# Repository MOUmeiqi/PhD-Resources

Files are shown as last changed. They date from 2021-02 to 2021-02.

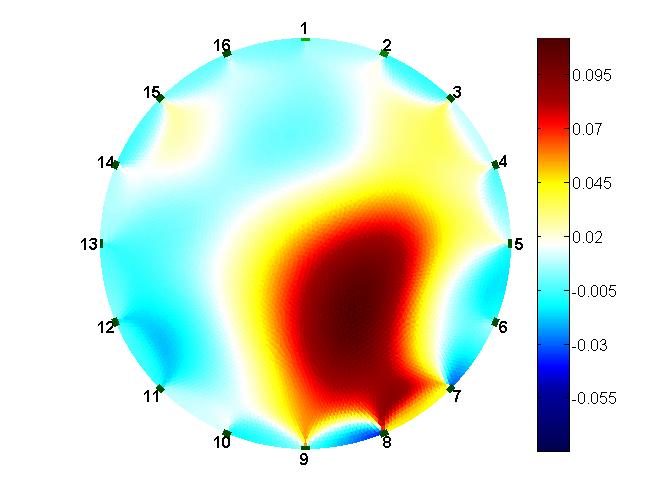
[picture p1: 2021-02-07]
Misc. Images/repeatability/r4/r42.jpg

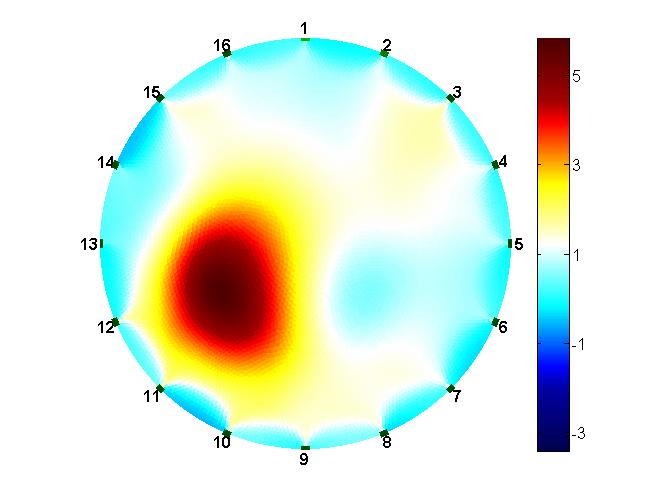
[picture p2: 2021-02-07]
Misc. Images/6-r64n.jpg

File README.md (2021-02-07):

# PhD-Resources
Source code repository for PhD on OCDM-aEITS

*** README ***

This repository (repo) contains the source code and some experimental results acquired during research of the thesis titled "Absolute Electrical Impedance Tomography and Spectroscopy - An Orthogonal Chirp Division Multiplexed (OCDM) Approach"
This thesis was authored by: Ezra Luke America and presented to the University of Cape Town for fulfilment of a Doctorate of Philosophy in Electrical Engineering.

The repo separated into four streams:
1) Source Codes
2) Misc. Experimental Results
3) Schematics
4) Misc. Images

*** Codes ***
The source codes components of the repo holds the source files that were used for the Arduino, MATLAB, uDAQ, and FPGA.
The code for the Arduino was used to control the system wide multiplexing.
The code for MATLAB was used to control the entire system and reconstruct images.
The code for the uDAQ_test_scripts were used to control a data acquisition card when initial tests were performed.
The code for the VHDL_CODE were used to control the ADC/DAC data acquisition board and FPGA.

*** Misc. Experimental Results ***
This folder contains 8 internal folders that hold a measurement frame for eight different positions of an anomaly.
To test this data, import the data to the MATLAB image_reconstruction code in the MATLAB folder.

*** Schematics ***
The schematics folder contains some system design schematics.

*** Misc. Images ***
This folder contains some reconstructed images using higher element FEM models.

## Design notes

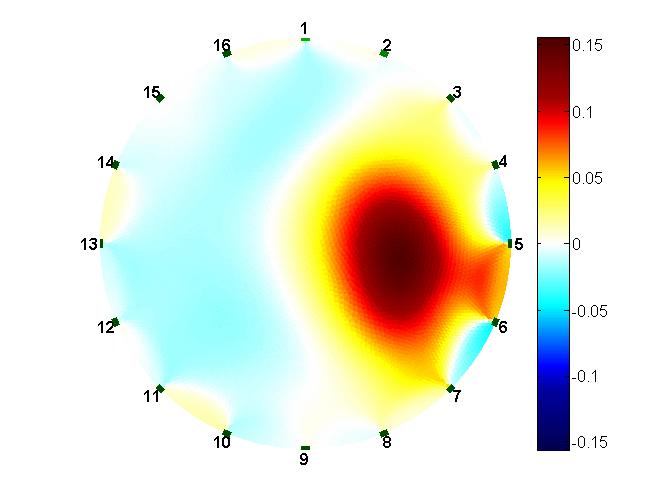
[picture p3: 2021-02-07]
Misc. Images/repeatability/r3/r35.jpg

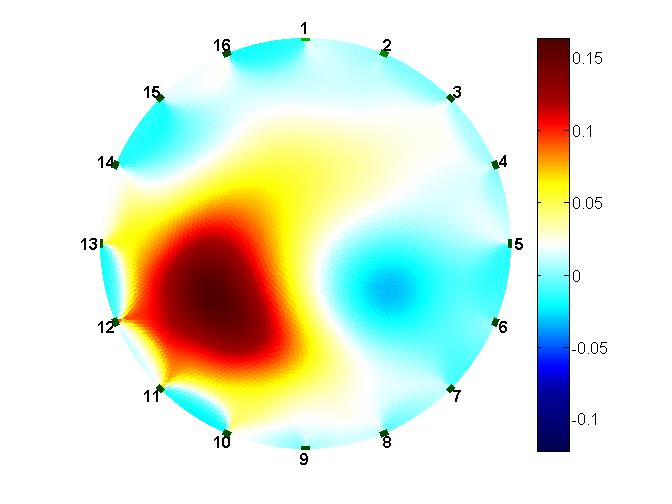
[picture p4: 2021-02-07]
Misc. Images/repeatability/r6/r62.jpg

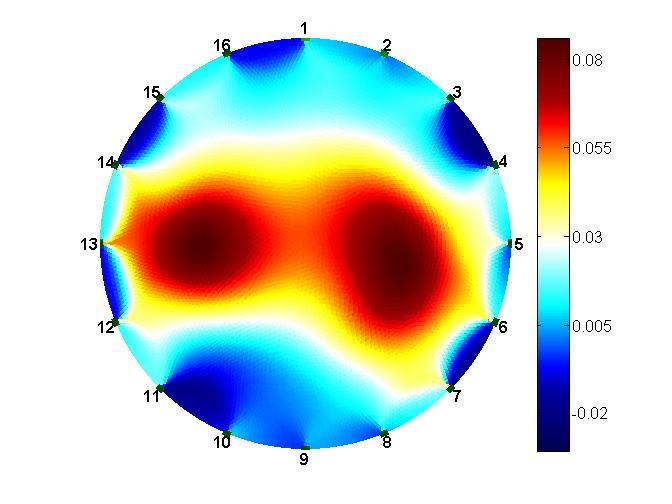
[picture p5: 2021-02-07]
Misc. Images/rdavg.jpg

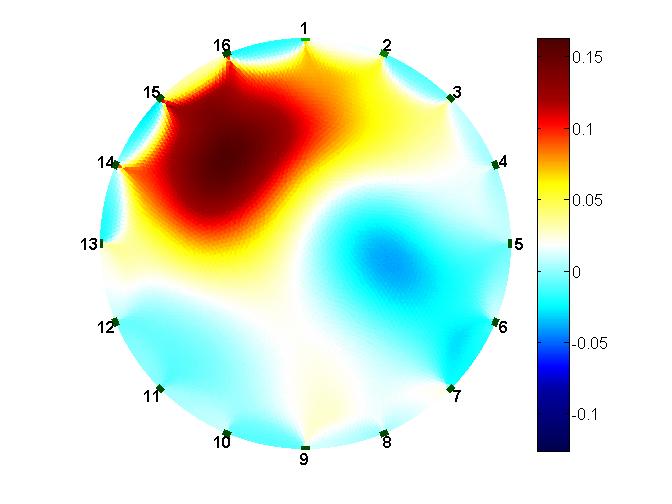
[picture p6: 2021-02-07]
Misc. Images/repeatability/r8/r82.jpg

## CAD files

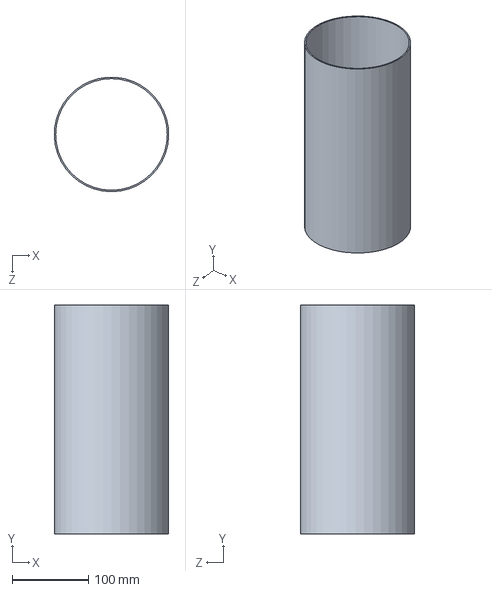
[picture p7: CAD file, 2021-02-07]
Schematics/electrodes/Part1.SLDPRT
149.9 x 300.0 x 149.8 mm

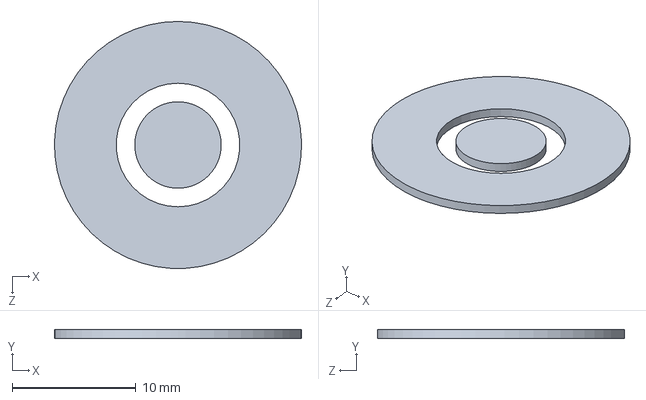
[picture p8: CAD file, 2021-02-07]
Schematics/electrodes/Part2.SLDPRT
20.0 x 0.7 x 20.0 mm

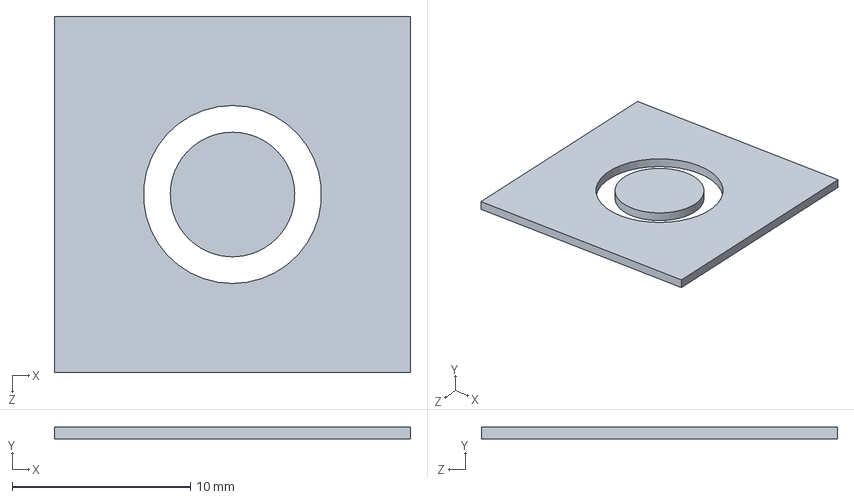
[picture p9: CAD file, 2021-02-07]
Schematics/electrodes/Part3.SLDPRT
20.0 x 0.7 x 20.0 mm

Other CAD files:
VHDL_CODE/db/step1_auto_stripped.stp
VHDL_CODE/step1_auto_stripped.stp
Schematics/electrodes/Circular Compound Internal Electrodes.DXF
VHDL_CODE/step1.stp
Schematics/electrodes/Uniform Current Density Electrodes.DXF
Schematics/electrodes/Circular Compound Internal Electrodes.SLDDRW
Schematics/electrodes/Uniform Current Density Electrodes.SLDDRW

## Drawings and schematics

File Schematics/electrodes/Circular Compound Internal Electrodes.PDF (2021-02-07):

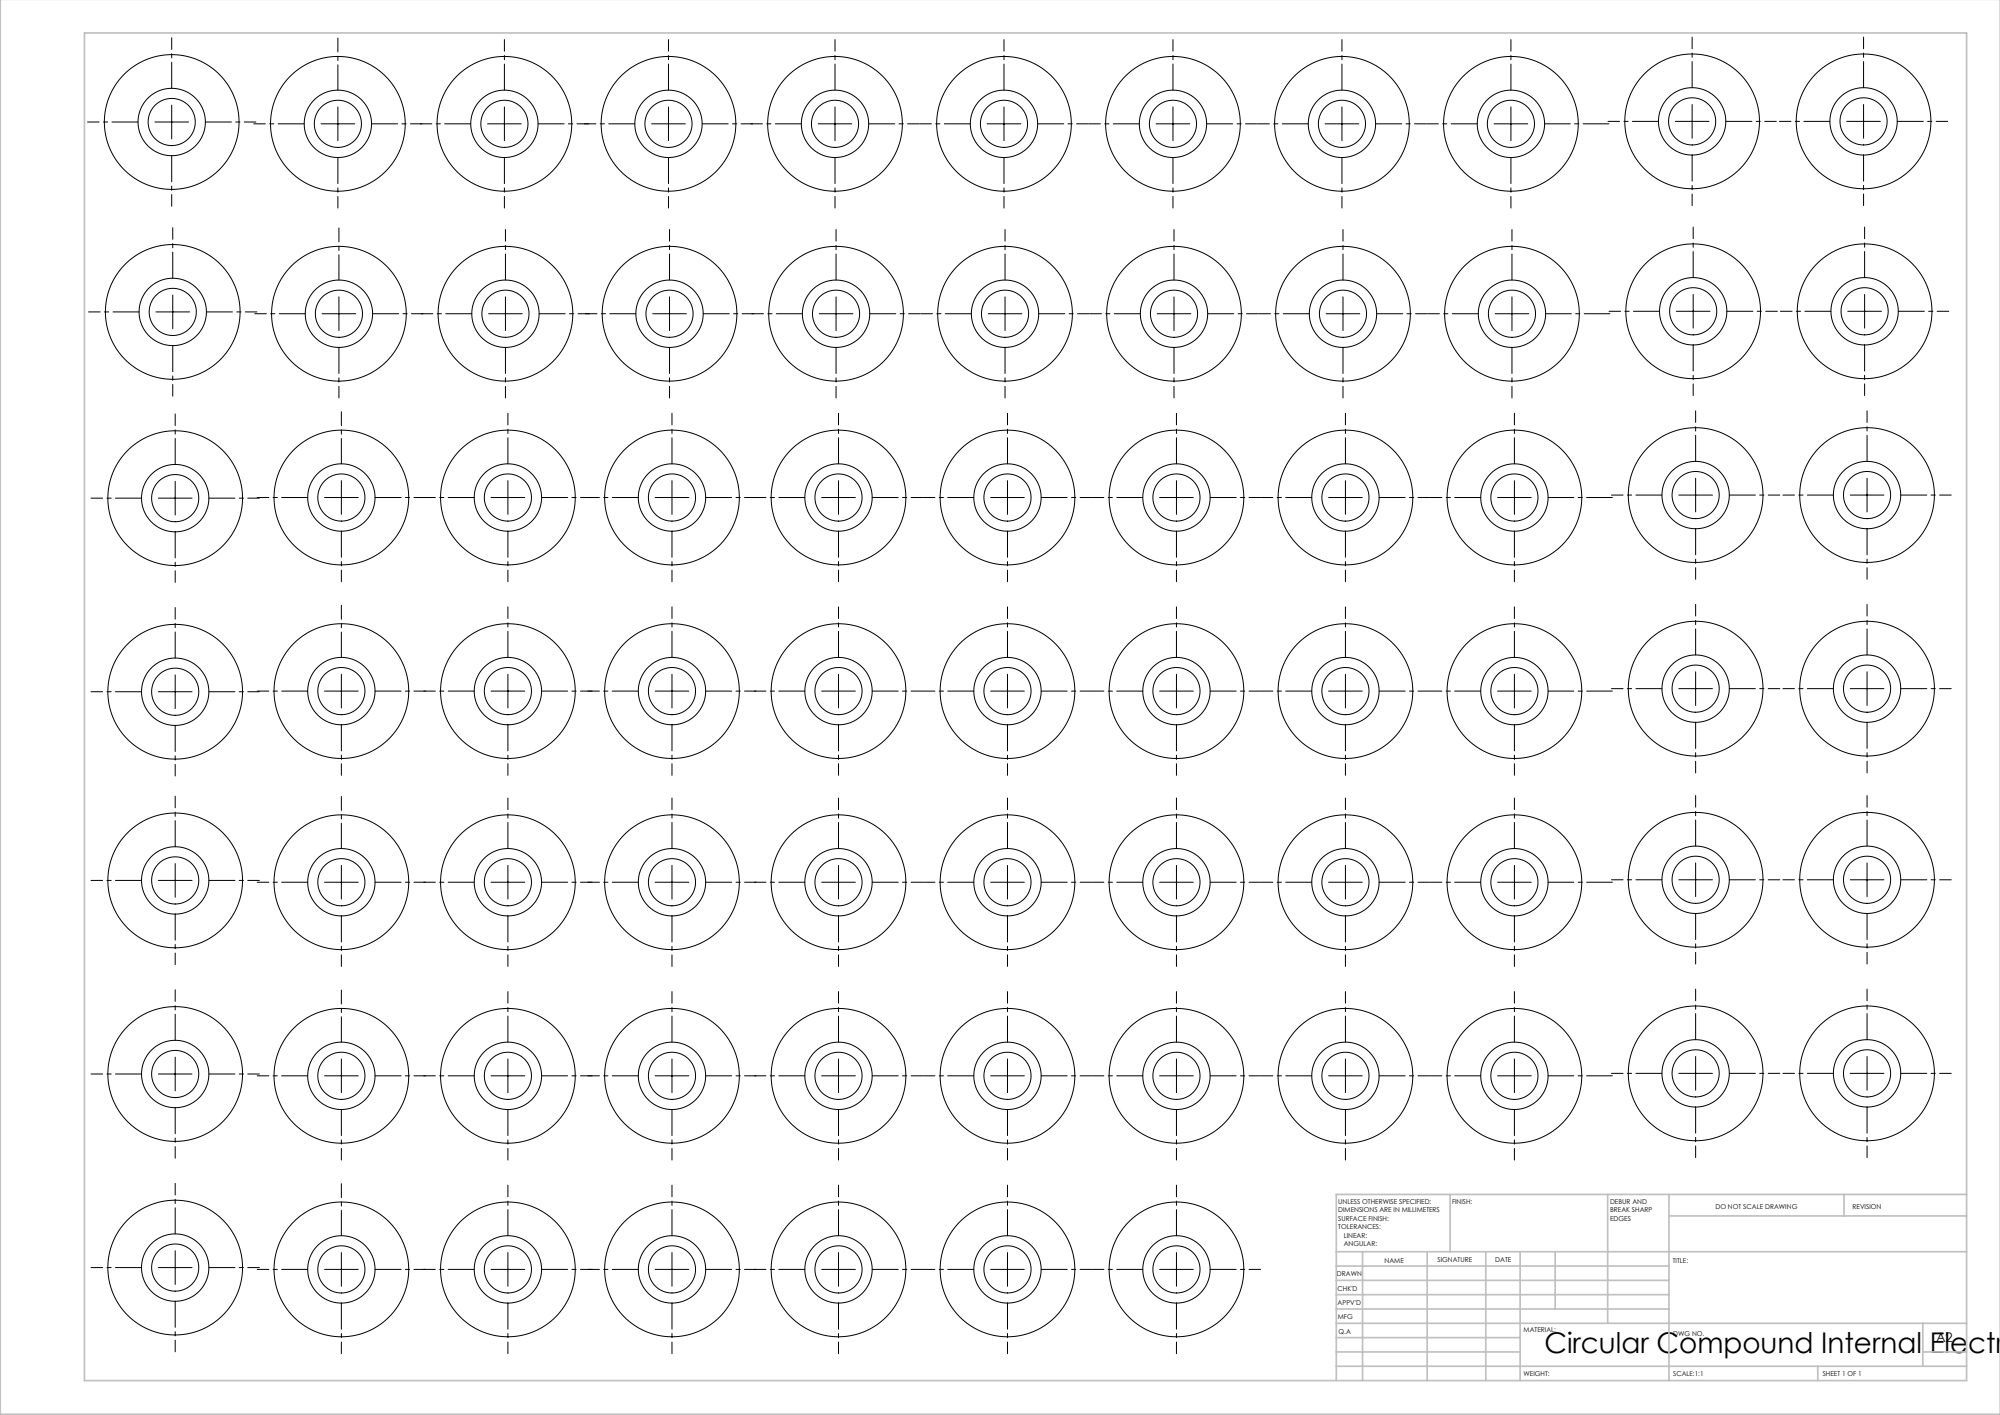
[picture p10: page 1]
SCALE:1:1; SHEET 1 OF 1; DO NOT SCALE DRAWING; REVISION; DEBUR AND BREAK SHARP; UNLESS OTHERWISE SPECIFIED:; FINISH:

DIMENSIONS ARE IN MILLIMETERS
SURFACE FINISH:
TOLERANCES:
LINEAR:
ANGULAR:

NAME | SIGNATURE | DATE | | | | TITLE:

DRAWN
CHK'D
APPV'D
MFG
Q.A | | | | MATERIAL: | DWG NO. | A2

Circular Compound Internal Electrodes

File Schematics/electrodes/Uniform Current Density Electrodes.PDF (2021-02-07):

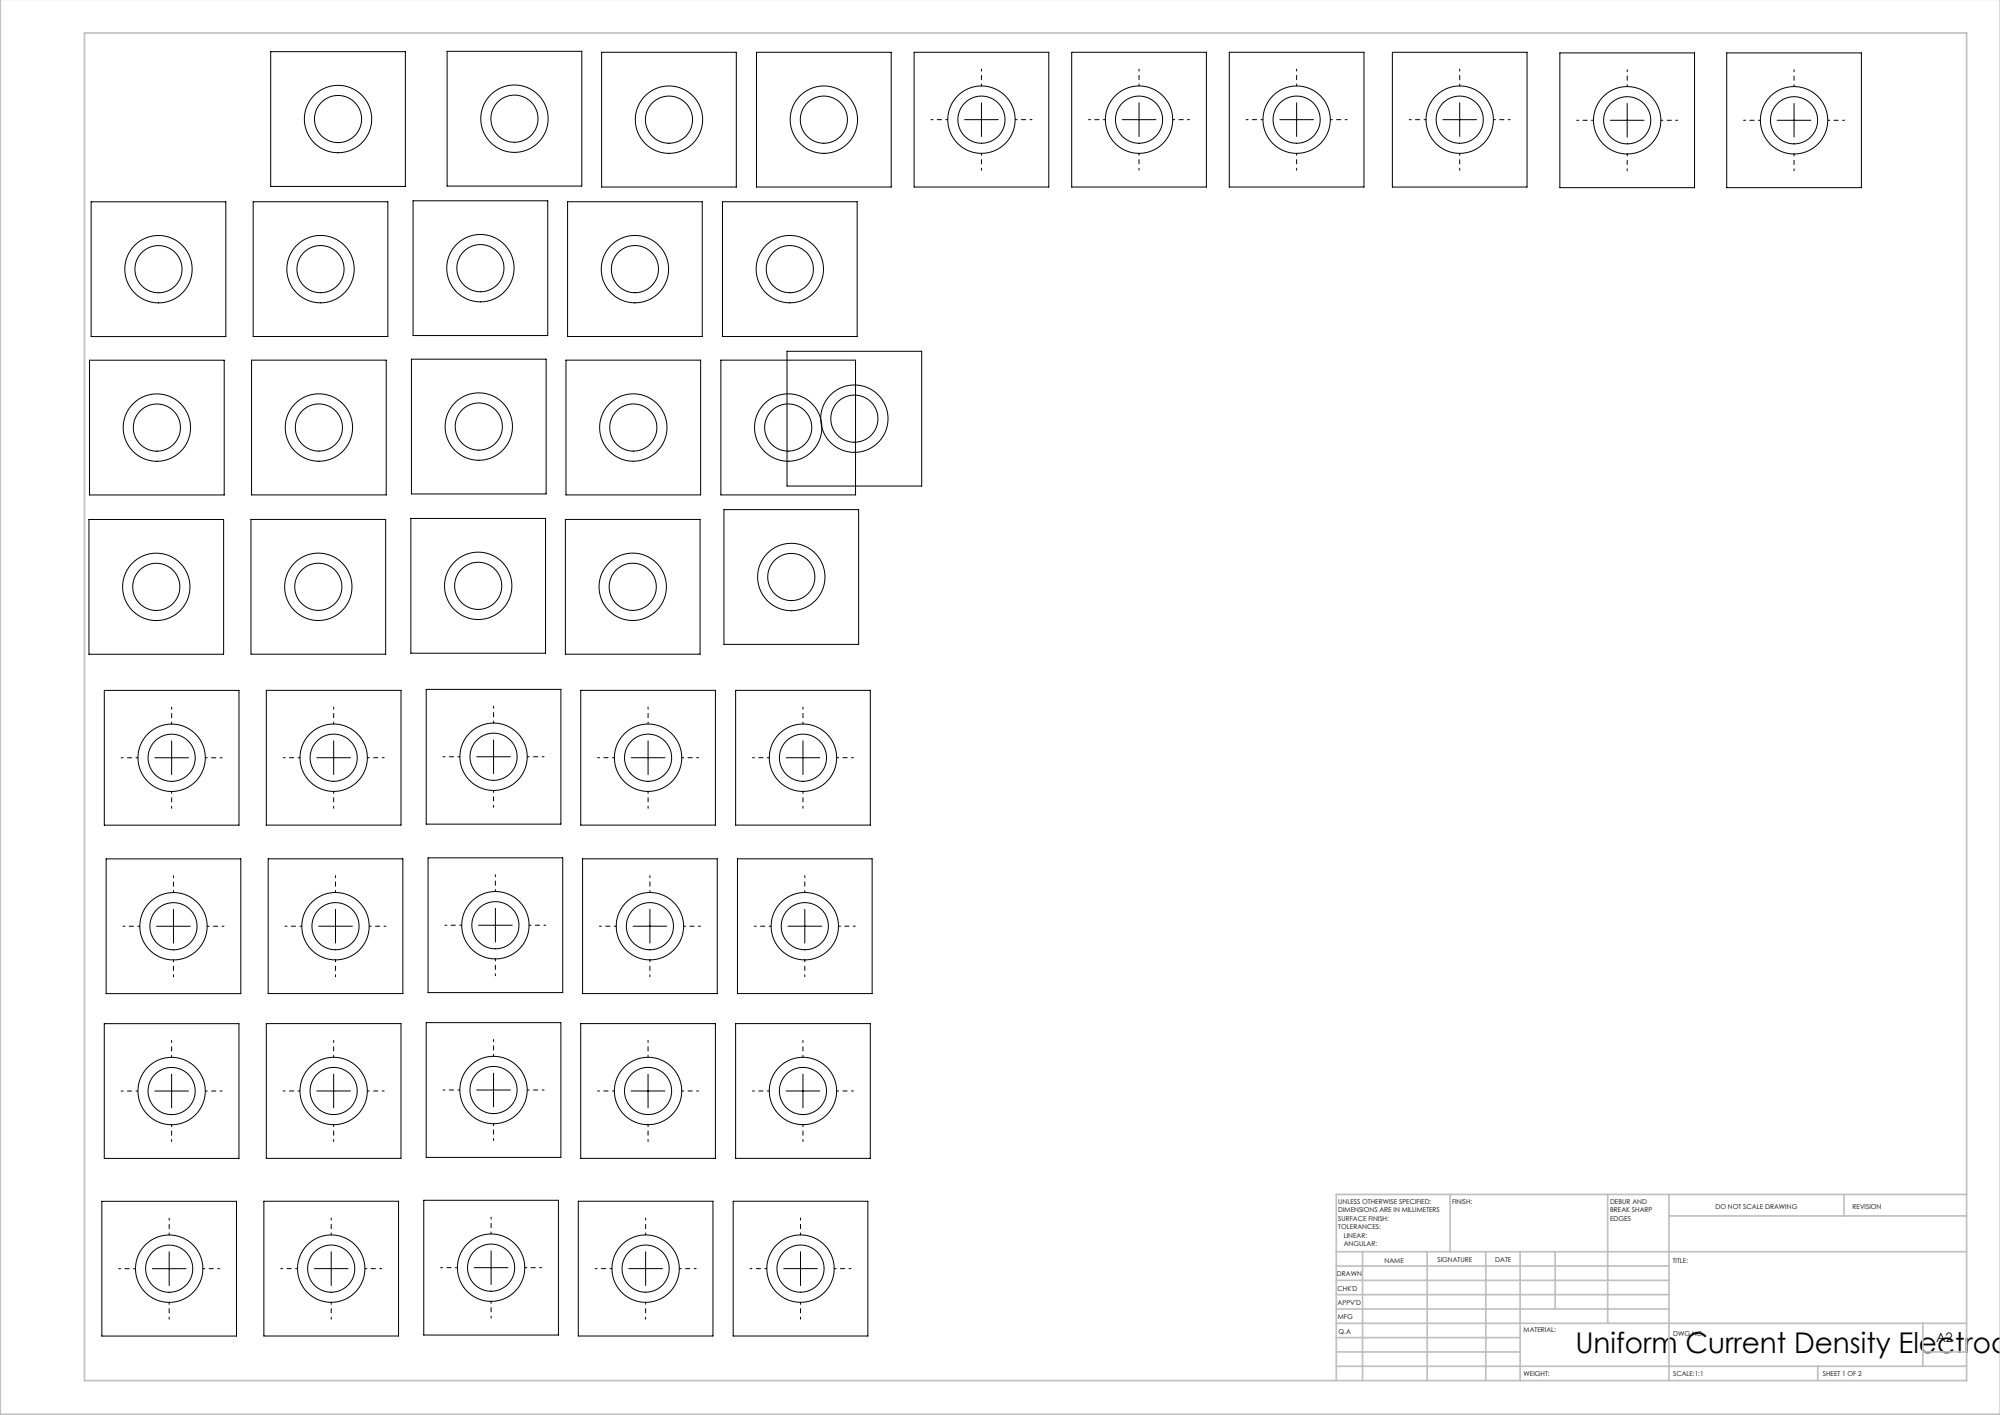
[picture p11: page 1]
SCALE:1:1; SHEET 1 OF 2; DO NOT SCALE DRAWING; REVISION; DEBUR AND BREAK SHARP; UNLESS OTHERWISE SPECIFIED:; FINISH:

DIMENSIONS ARE IN MILLIMETERS
SURFACE FINISH:
TOLERANCES:
LINEAR:
ANGULAR:

NAME | SIGNATURE | DATE | | | | TITLE:
Q.A | | | | Uniform Current Density Electrodes WEIGHT: MATERIAL: | DWG NO. | A2

DRAWN
CHK'D
APPV'D
MFG

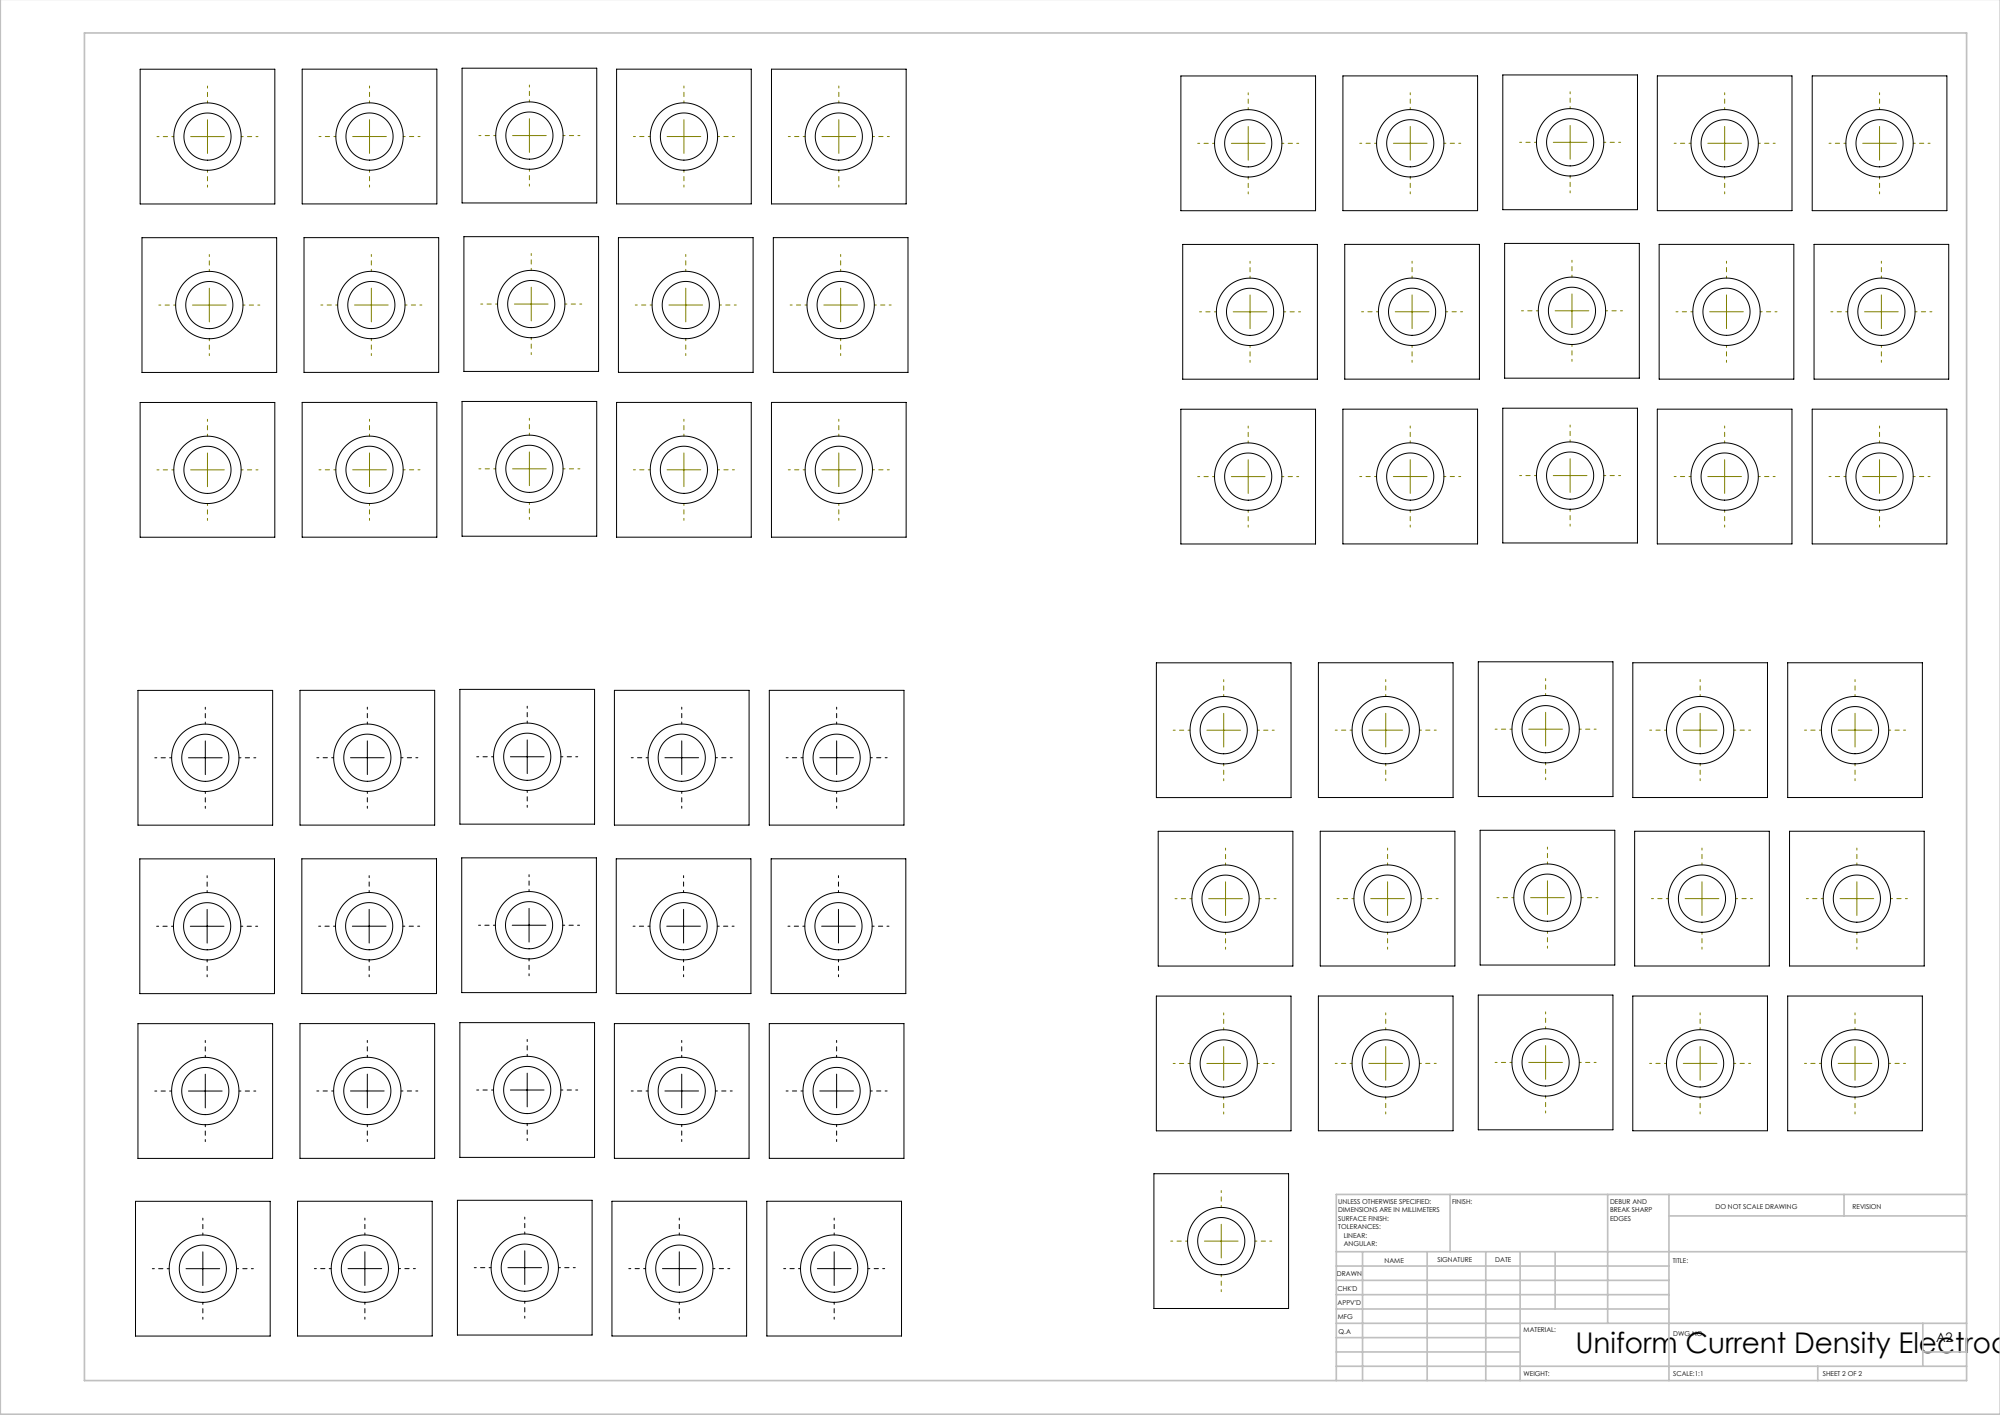
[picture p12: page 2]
SCALE:1:1; SHEET 2 OF 2; DO NOT SCALE DRAWING; REVISION; DEBUR AND BREAK SHARP; UNLESS OTHERWISE SPECIFIED:; FINISH:

DIMENSIONS ARE IN MILLIMETERS
SURFACE FINISH:
TOLERANCES:
LINEAR:
ANGULAR:

NAME | SIGNATURE | DATE | | | | TITLE:
Q.A | | | | Uniform Current Density Electrodes WEIGHT: MATERIAL: | DWG NO. | A2

DRAWN
CHK'D
APPV'D
MFG

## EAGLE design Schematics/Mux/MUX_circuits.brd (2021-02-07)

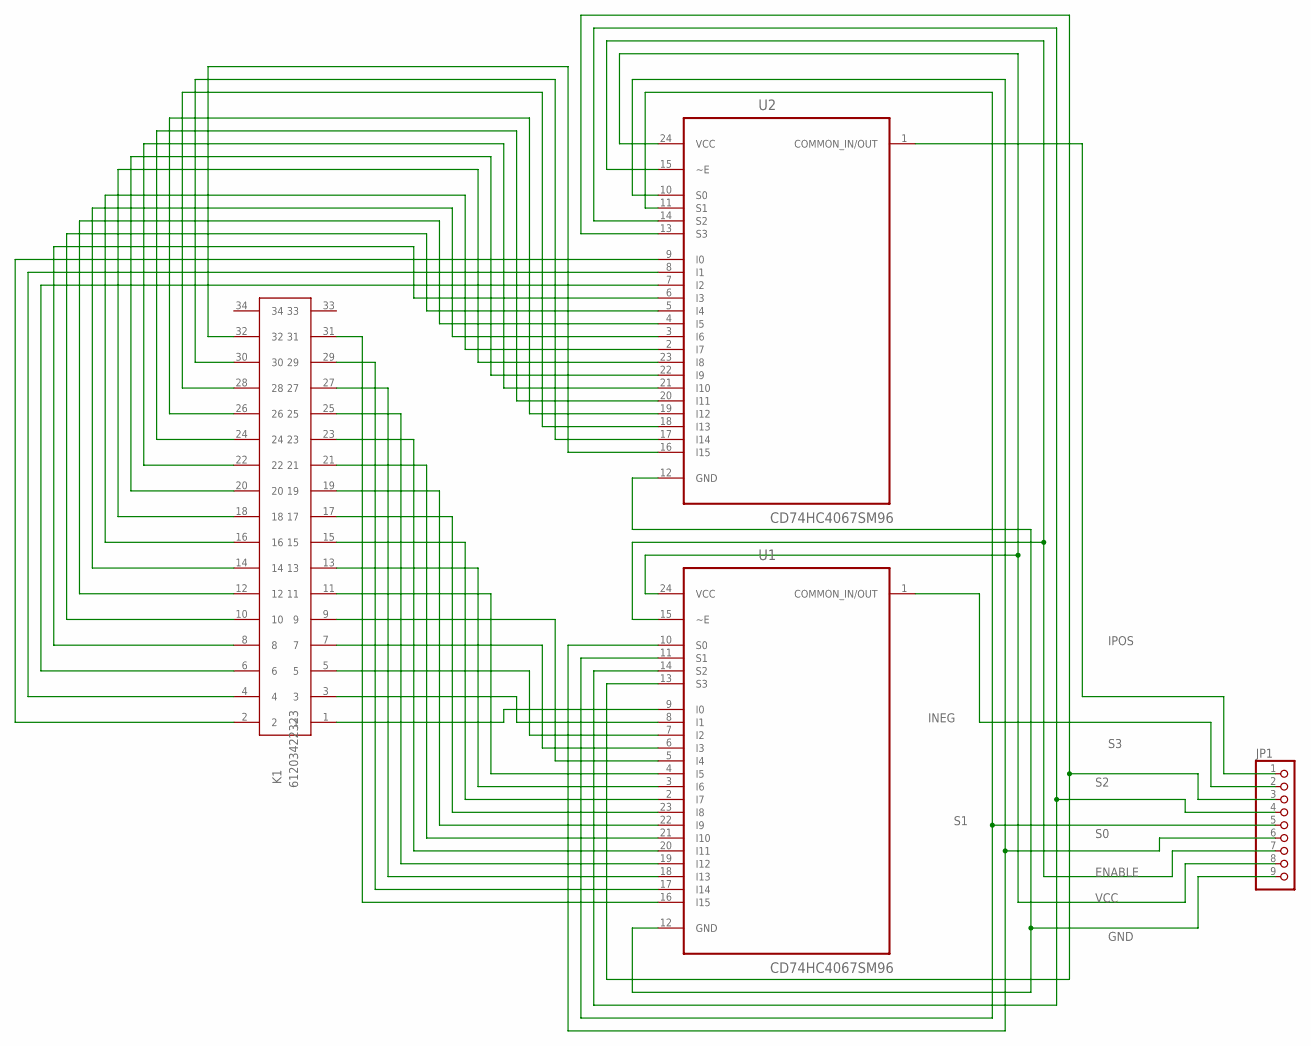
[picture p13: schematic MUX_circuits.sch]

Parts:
JP1: PINHD-1X9; 1X09
K1: 61203422323
U1, U2: CD74HC4067SM96; SOP65P780X200-24N

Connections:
ENABLE: JP1.7, U1.15 (~E), U2.15 (~E)
GND: JP1.9, U1.12 (GND), U2.12 (GND)
INEG: JP1.2, U1.1 (COMMON_IN/OUT)
IPOS: JP1.1, U2.1 (COMMON_IN/OUT)
unnamed: K1.1, U1.9 (I0)
unnamed: K1.2, U2.9 (I0)
unnamed: K1.3, U1.8 (I1)
unnamed: K1.5, U1.7 (I2)
unnamed: K1.7, U1.6 (I3)
unnamed: K1.9, U1.5 (I4)
unnamed: K1.11, U1.4 (I5)
unnamed: K1.13, U1.3 (I6)
unnamed: K1.15, U1.2 (I7)
unnamed: K1.17, U1.23 (I8)
unnamed: K1.19, U1.22 (I9)
unnamed: K1.21, U1.21 (I10)
unnamed: K1.23, U1.20 (I11)
unnamed: K1.25, U1.19 (I12)
unnamed: K1.27, U1.18 (I13)
unnamed: K1.29, U1.17 (I14)
unnamed: K1.31, U1.16 (I15)
unnamed: K1.4, U2.8 (I1)
unnamed: K1.6, U2.7 (I2)
unnamed: K1.8, U2.6 (I3)
unnamed: K1.10, U2.5 (I4)
unnamed: K1.12, U2.4 (I5)
unnamed: K1.14, U2.3 (I6)
unnamed: K1.16, U2.2 (I7)
unnamed: K1.18, U2.23 (I8)
unnamed: K1.20, U2.22 (I9)
unnamed: K1.22, U2.21 (I10)
unnamed: K1.24, U2.20 (I11)
unnamed: K1.26, U2.19 (I12)
unnamed: K1.28, U2.18 (I13)
unnamed: K1.30, U2.17 (I14)
unnamed: K1.32, U2.16 (I15)
S0: JP1.6, U1.10 (S0), U2.10 (S0)
S1: JP1.5, U1.11 (S1), U2.11 (S1)
S2: JP1.4, U1.14 (S2), U2.14 (S2)
S3: JP1.3, U1.13 (S3), U2.13 (S3)
VCC: JP1.8, U1.24 (VCC), U2.24 (VCC)

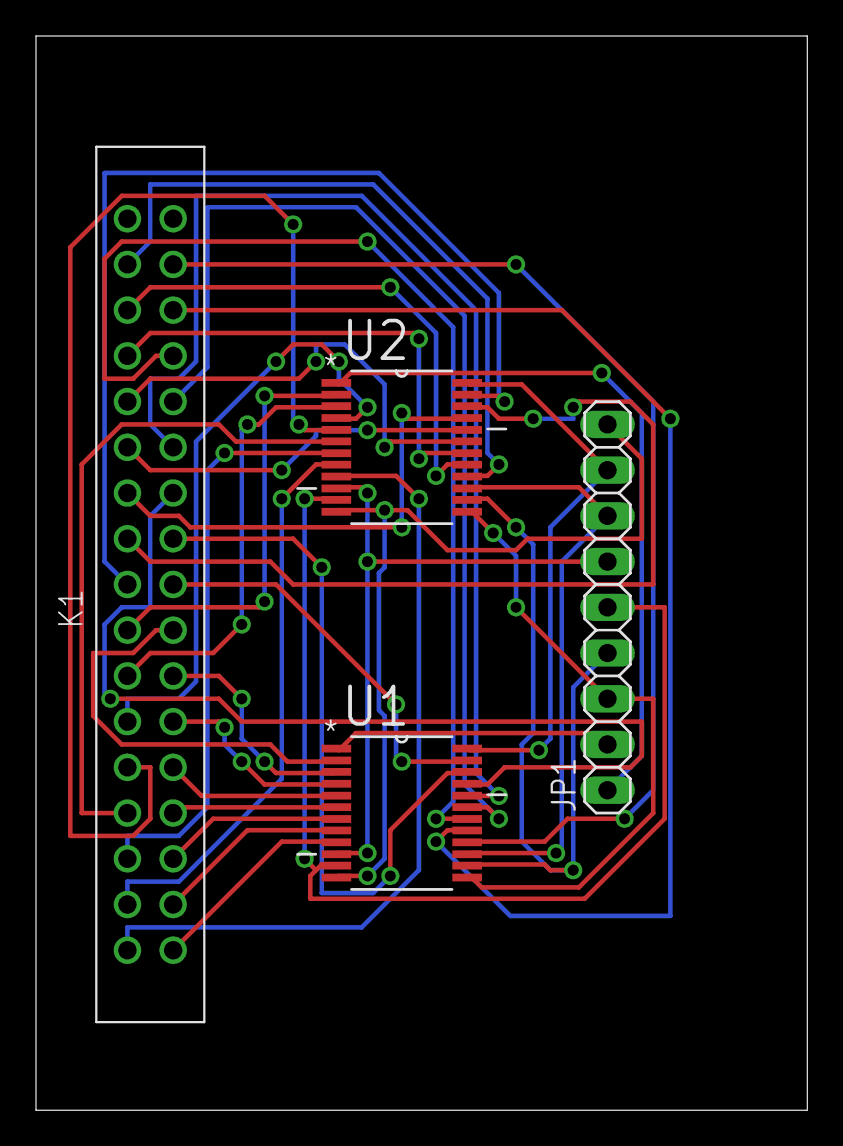
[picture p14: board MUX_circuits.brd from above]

Board: 2 copper layers, 42.9 x 59.7 mm, 4 parts (0 on the bottom side), 41 nets.

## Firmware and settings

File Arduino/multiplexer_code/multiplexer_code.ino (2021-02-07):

#include <stdint.h>

/*macros*/
/********************************************************/
//  set pin low
#define output_low(pin) digitalWrite(pin, LOW)

// set pin high
#define output_high(pin) digitalWrite(pin, HIGH)

// return the state of pin
#define input(pin) digitalRead(pin)
/********************************************************/

// mux-pair pins
#define E 51
#define S3 49 //49
#define S2 47 //47
#define S1 45 //45
#define S0 43 //43

// demux-pair pins
#define E2 41
#define S32 39 //49
#define S22 37 //47
#define S12 35 //45
#define S02 33 //43


void setup() {
  Serial.begin(115200);
  establishContact();
  beginMeasure();
}

void loop()
{
  output_high(E);
  output_high(E2);
  int p = 1;
  for(byte counter = 0; counter <= 15; counter++)
  {
    MUX_SWITCH(counter);
    p++;
    for(byte counter2 = 0; counter2 <= 15; counter2++)
    {
      MUX_SWITCH2(counter2);
      boolean next = true;
      while(next)
      {
        char cont = Serial.read();
        if(cont == 'N')
        {
          next = false;
          Serial.print("Q");
        }
      } 
    }
  }
  output_high(E);
  output_high(E2);
  if(p = 16)
  {
    boolean q = true;
    while(q){
       
      if(Serial.available()){
        char z = Serial.read();
        if(z == 'Z'){
          q = false;

        }
      }  
    }
    p = 1; 
  }
}

// Change mux-pair pins
void MUX_SWITCH(byte switched){
  byte counterNEW = switched;
  output_high(E);
  int SwitchPos[] = {S3, S2, S1, S0};
  for(int k = 0; k<4 ; k++){
    output_low(E);
    if(bitRead(counterNEW, k)==1){
      output_high(SwitchPos[k]);
    }
    else{
      output_low(SwitchPos[k]);
    }
  }
}

// Change demux-pair pins
void MUX_SWITCH2(byte switched){
  output_high(E2);
  int SwitchPos2[] = {S32, S22, S12, S02};
  for(int k = 0; k<4 ; k++){
    output_low(E2);
    if(bitRead(switched, k)==1){
      output_high(SwitchPos2[k]);
    }
    else{
      output_low(SwitchPos2[k]);
    }
  }
}

// Communicate with the serial
void establishContact()
{
  while(Serial.available()<= 0)
  {
    Serial.println('A');
    delay(300);
  }
}

// Configure Arduino pins
void beginMeasure()
{
   if(Serial.available())
  {
    int SwitchPos[] = {S3, S2, S1, S0};
    int SwitchPos2[] = {S32, S22, S12, S02};
    boolean h = true;
    while(h)
    {
      char m = Serial.read();
      if(m == 'M')
      {
         pinMode(E,OUTPUT);
         pinMode(E2,OUTPUT);
         for(int i = 0; i<4; i++)
         {
            pinMode(SwitchPos[i], OUTPUT);
            pinMode(SwitchPos2[i], OUTPUT);
         }
         h = false;
         Serial.println(MUXdelay);
      }
    }       
  }      
} 

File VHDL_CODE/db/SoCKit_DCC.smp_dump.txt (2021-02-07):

State Machine - |SoCKit_DCC|SoCKit_DCC_TOP:SoCKit_DCC_TOP_ins|FIR_3MHZ_low:FIR_3MHZ_low_inst|FIR_3MHZ_low_0002:fir_3mhz_low_inst|FIR_3MHZ_low_0002_ast:FIR_3MHZ_low_0002_ast_inst|auk_dspip_avalon_streaming_sink_hpfir:sink|sink_state
Name sink_state.end1 sink_state.st_err sink_state.run1 sink_state.stall sink_state.start 
sink_state.start 0 0 0 0 0 
sink_state.stall 0 0 0 1 1 
sink_state.run1 0 0 1 0 1 
sink_state.st_err 0 1 0 0 1 
sink_state.end1 1 0 0 0 1 

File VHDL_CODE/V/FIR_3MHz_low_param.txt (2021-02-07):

fc_version   : 3.3
blank_gen    : READ
---new_set---
alpha     : 0
fc1       : 1.25e+006
fc2       : 3.75e+006
length    : 37
samp_rate : 1e+007
win_type  : NON 
flt_type  : LPF 
---end_set---
coef_bit_width  : 17
coef_conv_sel   : AUTO 
coef_pow2       : FALSE 
coef_sbf_left   : 0
coef_sbf_right  : 0
data_type       : USN 
in_bit_width    : 14
in_sbf_lt       : 0
in_sbf_rt       : 0
num_ch          : 1
out_calc_basis  : 0
out_full_chk    : 0
out_msb_rad     : MSB_SAT 
out_lsb_rad     : LSB_TRN 
out_lose_lsb    : 22
out_lose_msb    : 0
out_sbf_chk     : 0
arch_struct_sel  : 3
arch_data_store  : 0
arch_coef_store  : 0
arch_no_ctrl     : 0
arch_reload_coef : 0
arch_reload_coef_sgl_clock : 0
arch_num_mbs     : 2
arch_no_sym      : 0
num_bank_set    : 1
num_mac         : 0
num_cycles      : 1
arch_pipeline      : 1
poly_type       : 0
poly_fact       : 1
device_family   : 30
use_dsp_block   : 0
m_file_gen      : 1
ver_file_gen    : 0
is_reg_test     : 0
vec_file_gen    : 1
vec_clk_per     : 10
mod_param       : 0
blank_num_sys   : 0
rate_ctrl       : RATE_CTRL_OFF 
atlantic_out    : MASTER 
atlantic_in     : MASTER 
fir_bit_width   : 36
num_coef_mem     : 5
coef_mem_width  : 15
coef_mem_addr   : 4
num_coef_one_mem : 1
fmax			: 0
num_lc			: 2626
num_m4k			: 0
num_m512			: 0
num_MRAM			: 0
num_mul			: 0
num_mul_bit		: 9
num_MLAB			: 0

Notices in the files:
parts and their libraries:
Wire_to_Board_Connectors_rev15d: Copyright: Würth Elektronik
